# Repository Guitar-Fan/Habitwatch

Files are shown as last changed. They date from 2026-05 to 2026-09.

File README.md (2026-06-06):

# Habitwatch

This is the Habitwatch, a custom designed smartwatch for keep track of habits. It uses an Xiao ESP-32-C6 4.0 development board, compact enough to fit in a small sized enclosure, while having many features. The main function is a highly customizable reminder/alarm system, that works along side a integrated vibration motor to remind you to keep all habits you want. The firmware also allows users to customize the motor to produce a custom monophonic ringtone. Extra features include connectivity with devices via wifi, bluetooth, etc... All electronics are smarly housed in a custom-designed 3D-printed compact enclosure (with a reasonable size for a watch).

I made this project because I know first-hand the difficulty of upholding good habits, and wanted to make a project to help out with a common life problem. I also wanted this watch to be truely useful to everyday life.

## Images

### Schematic
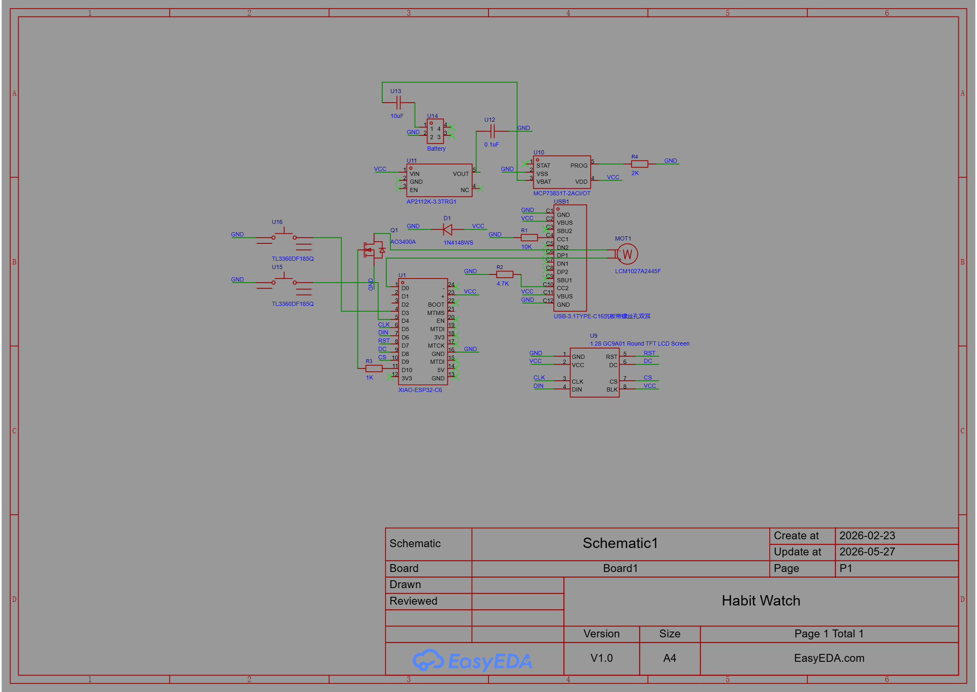
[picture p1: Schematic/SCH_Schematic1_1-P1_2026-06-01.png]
Wiring Diagram

*Complete wiring diagram showing all connections*

### PCB Design
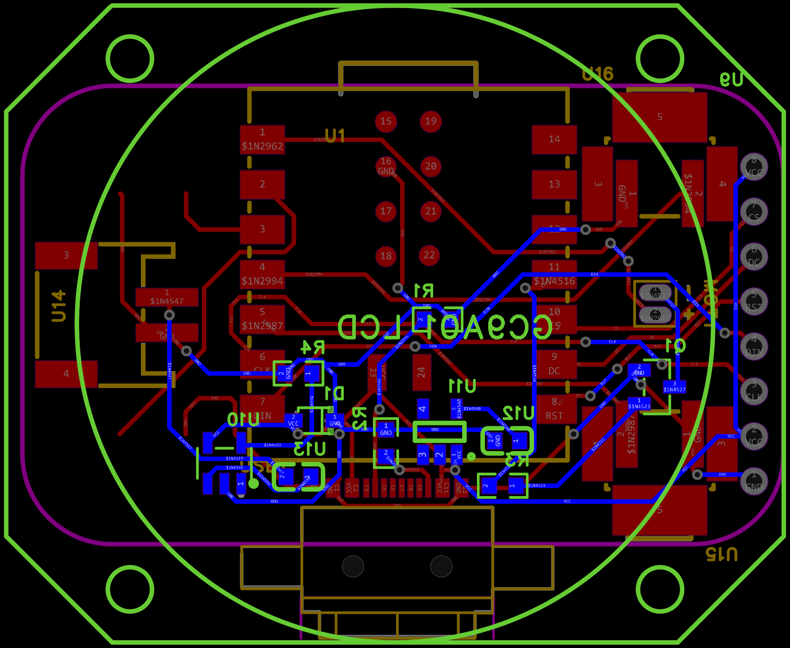
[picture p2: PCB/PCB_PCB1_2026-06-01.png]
PCB Layout

*Custom PCB design for the Habitwatch circuit*

### 3D Enclosure - Front
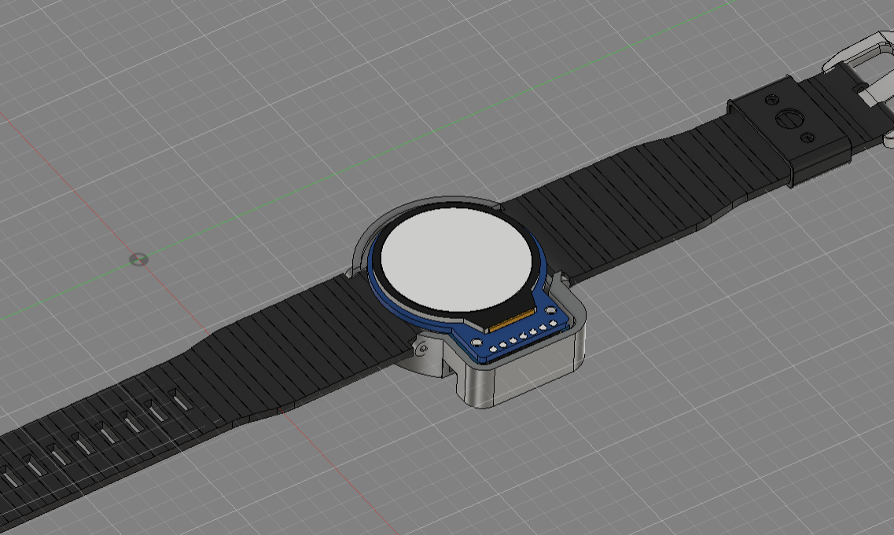
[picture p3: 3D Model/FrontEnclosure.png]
3D Build Model Front with Enclosure

*Custom-designed 3D-printed enclosure front view*

### 3D Enclosure - Back
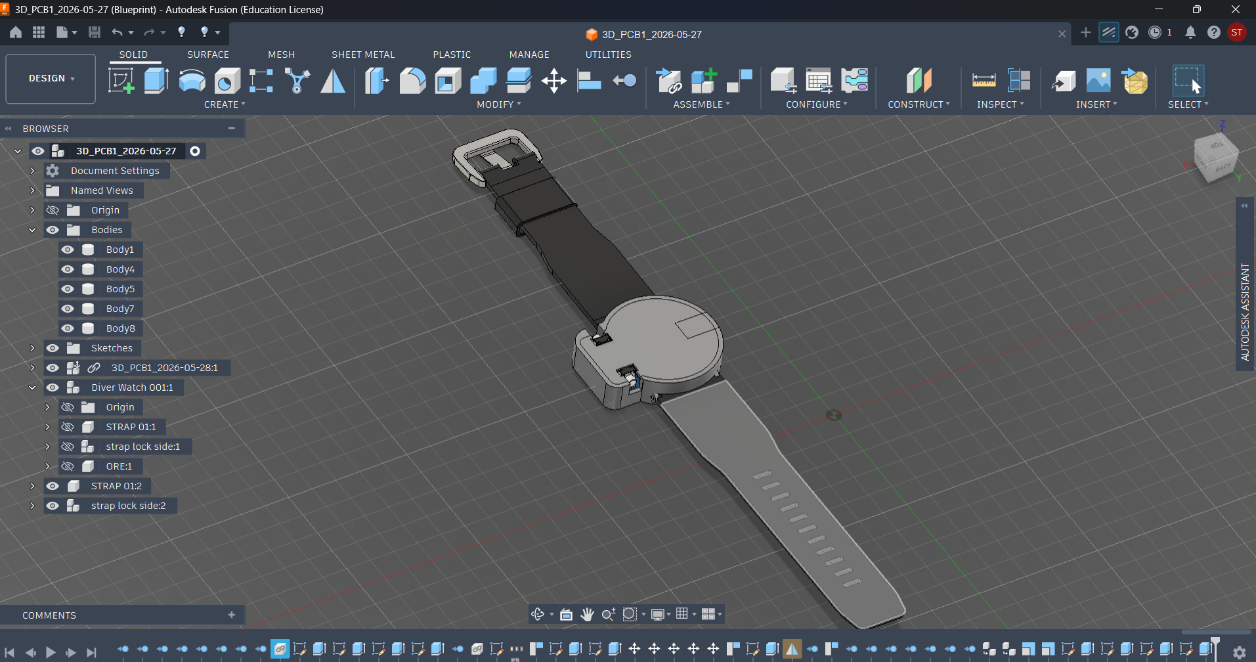
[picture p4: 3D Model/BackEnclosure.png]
3D Build Model Back with Enclosure

*Custom-designed 3D-printed enclosure back view*

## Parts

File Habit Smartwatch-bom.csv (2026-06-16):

Name | Purpose | Quantity | Total Cost (USD) | Link | Distributor
CR0603-JW-102ELF | 1K resistor | 1 | 0.10 | https://www.digikey.com/en/products/detail/bourns-inc/CR0603-JW-102ELF/3741004 | Digikey
CR0603-JW-202ELF | 2K resistor | 1 | 0.10 | https://www.digikey.com/en/products/detail/bourns-inc/CR0603-JW-202ELF/3784319 | Digikey
CR0603-JW-472ELF | 4.7K Resistor | 1 | 0.10 | https://www.digikey.com/en/products/detail/bourns-inc/CR0603-JW-472ELF/3593210 | Digikey
CR0603-FX-1002ELF | 10K Chip Resistor | 1 | 0.10 | https://www.digikey.com/en/products/detail/bourns-inc/CR0603-FX-1002ELF/3593188 | Digikey
1N4148WS | Diode | 1 | 0.18 | https://www.digikey.com/en/products/detail/onsemi/1n4148ws/1873805 | Digikey
AP2112K-2.5TRG1 | Voltage Regulator | 1 | 0.23 | https://www.digikey.com/en/products/detail/diodes-incorporated/AP2112K-2-5TRG1/5305549 | Digikey
MCP73831T-2ACI/OT | Battery IC | 1 | 0.76 | https://www.digikey.com/en/products/detail/microchip-technology/mcp73831t-2aci-ot/964301 | Digikey
10164359-00011LF | USB-C Receptacle | 1 | 0.48 | https://www.digikey.com/en/products/detail/amphenol-cs-fci/10164359-00011LF/18443702 | Digikey
3.7V 200mAh 602025 Lipo Battery Rechargeable Lithium Polymer ion Battery Pack with PH2.0mm JST Connector | Lipo Battery | 1 | 6.99 | https://www.amazon.com/battery-Rechargeable-Lithium-Polymer-Connector/dp/B07C9R84QS?th=1 | Amazon
AO3400A | Mosfet | 1 | 0.52 | https://www.digikey.com/en/products/detail/alpha-omega-semiconductor-inc/ao3400a/1855772 | Digikey
FIT0774 | Vibration Motor | 1 | 0.99 | https://www.digikey.com/en/products/detail/dfrobot/FIT0774/14322639 | Digikey
TL3360DF185Q | Push Buttons | 2 | 2.20 | https://www.digikey.com/en/products/detail/e-switch/TL3360DF185Q/5816190 | Digikey
PCB | PCB | 1 | 5.10 |  | JLCPCB
GC9A01 TFT Display 1.28 Inch TFT LCD Display Module | Display | 1 | 3.04 | https://www.aliexpress.us/item/3256804295713253.html?curPageLogUid=uTnJoR09Xv6y | Aliexpress
XIAO ESP32C6 | Microcontroller | 1 | 9.28 | https://www.aliexpress.us/item/3256807240718259.html?gatewayAdapt=glo2usa4itemAdapt | Aliexpress

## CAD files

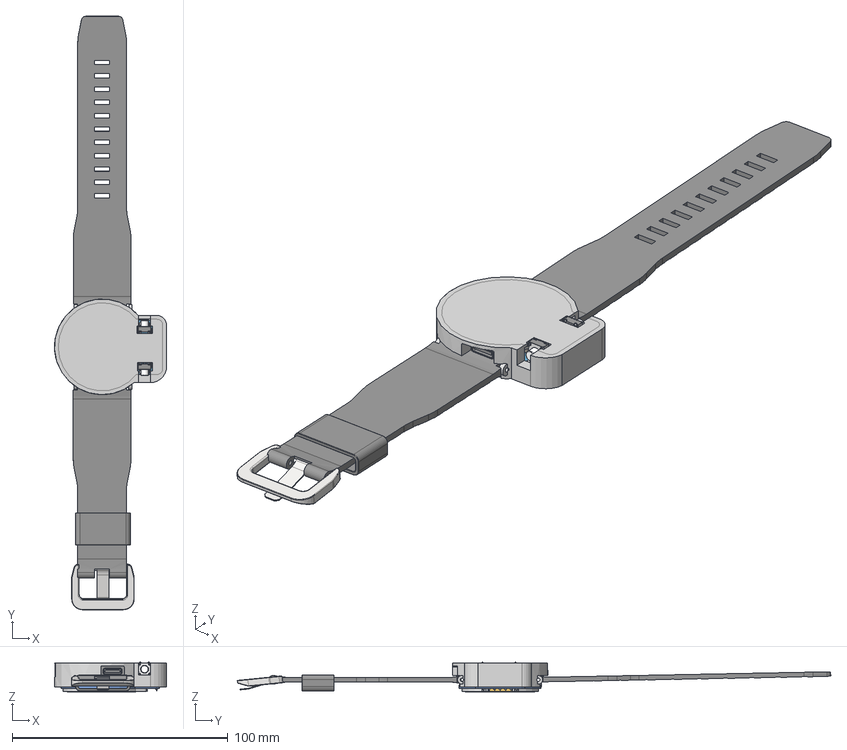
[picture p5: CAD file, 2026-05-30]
3D Model/HabitwatchEnclosureSTEP.step
51.9 x 275.3 x 13.9 mm

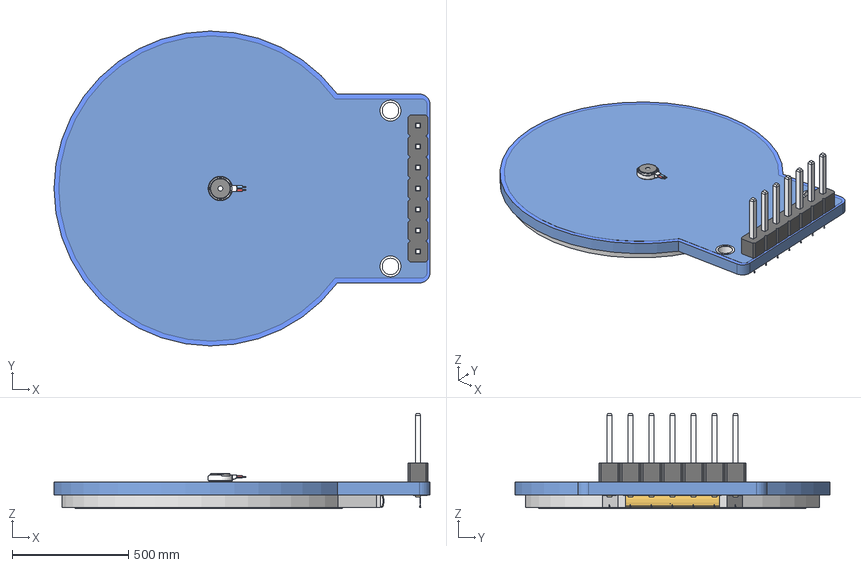
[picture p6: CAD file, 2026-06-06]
PCB/3D_PCB1_2026-06-01.step
1617.3 x 1354.2 x 409.2 mm
Board~56Qw
TopCopper~56Qw
BottomCopper~56Qw
TopSilkscreen~56Qw
BottomSilkscreen~56Qw
TopFpcStiffener~56Qw
BottomFpcStiffener~56Qw
R0603~R0603~7GvT x 4
SOT-23-3_L2.9-W1.3-P1.90-LS2.4-BR~SOT-23-3P_L2.9-W1.3-H1.0-LS2.4-P0.95~N2Kr
SOT-23-5_L3.0-W1.7-P0.95-LS2.8-BL~SOT-23-5_L2.9-W1.6-H1.1-LS2.8-P0.95~ODiN
VIBRATING-MOTOR-SMD_WELDING~VIBRATING-MOTOR-SMD_WELDING~XiWm
SOD-323_L1.8-W1.3-LS2.5-RD~SOD-323_L1.8-W1.3-LS2.5-RD~C2Tw
GC9A01 TFT LCD SCREEN~Teyleten Robot 1.28 Inch GC9A01 240x240 v1~5Ysm x 23
SOT-25-5_L2.9-W1.6-P0.95-LS2.8-BL~SOT-25-5_L2.9-W1.6-P0.95-LS2.8-BL~uqKM
C0603~C0603_L1.6-W0.8-H0.8~fYWC x 2
CONN-SMD_2.0-2PWT~CONN-SMD_2.0-2PWT~AiJI
LCC-14P_L17.7-W20.8-XIAO-ESP32-C6~Seeed Studio XIAO ESP32-C6~7Vn3 x 29
SW-SMD_TL3360BF185Q~SW-SMD_TL3360BF185Q~0CVZ x 2
USB-C-SMD_USB-3.1TYPE-C16~USB-C-SMD_USB-3.1TYPE-C16~z4gI

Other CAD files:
3D Model/Habitwatch Step 3d model with PCB.f3z

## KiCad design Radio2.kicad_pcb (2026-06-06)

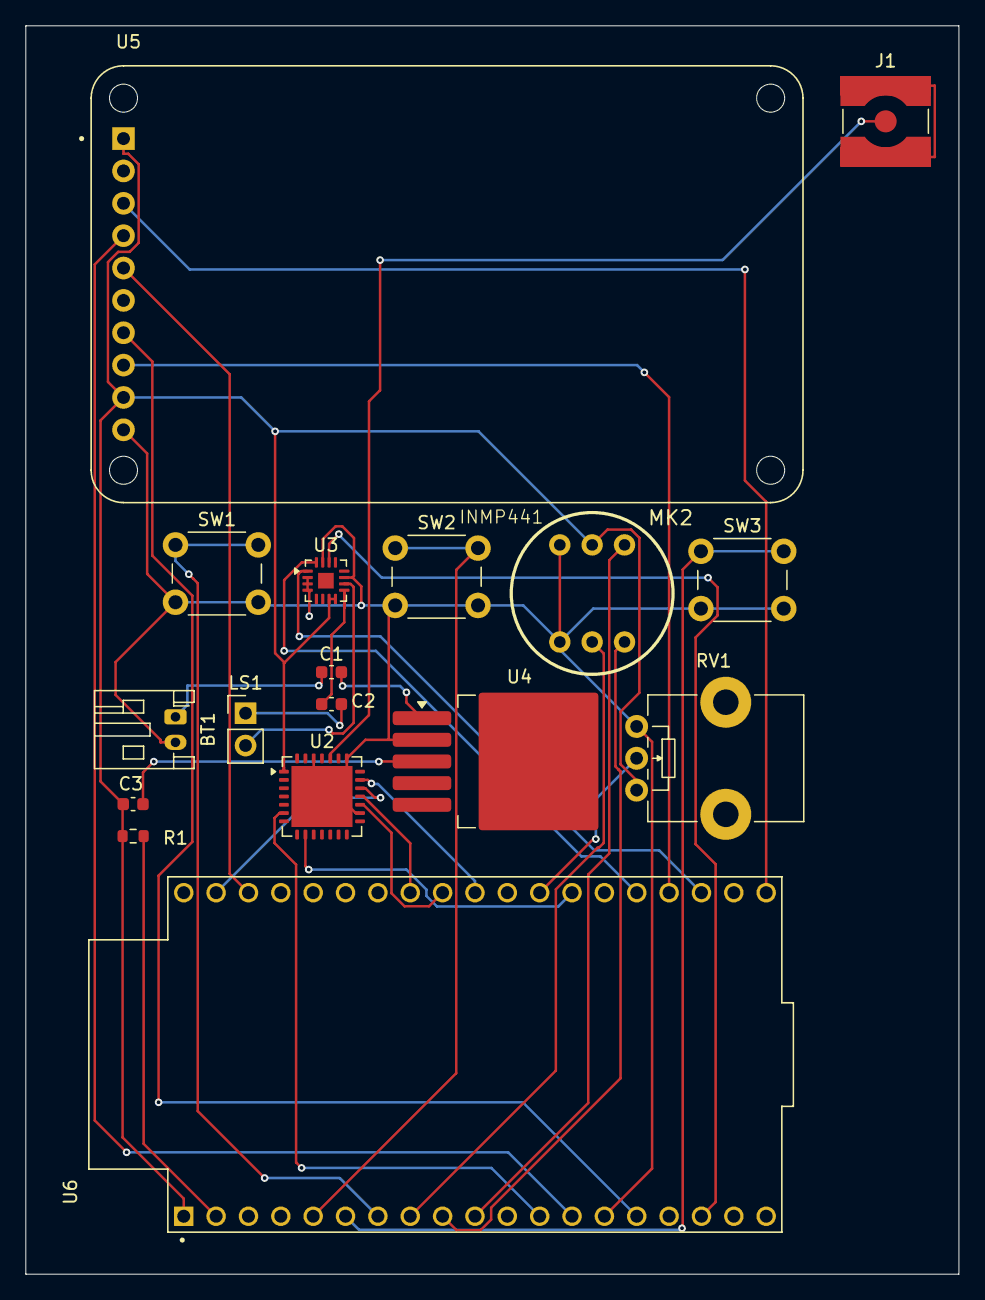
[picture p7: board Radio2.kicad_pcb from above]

Board: 2 copper layers, 73.2 x 98.0 mm, 17 parts (0 on the bottom side), 31 nets.

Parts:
BT1: LiPo 3.7V 2000mAh (Adafruit #2011); JST_PH_S2B-PH-K_1x02_P2.00mm_Horizontal
C1: 10 µF; C_0603_1608Metric
C2, C3: 100 nF; C_0603_1608Metric
J1: Conn_Coaxial; SMA_Amphenol_132134-10_Vertical
LS1: 8Ω 0.5W speaker; PinHeader_1x02_P2.54mm_Vertical
MK2: INMP441
R1: 10 kΩ; R_0603_1608Metric
RV1: R_Potentiometer; Potentiometer_Bourns_PTV09A-1_Single_Vertical
SW1, SW2, SW3: SW_Push; SW_PUSH_6mm
U2: SX1272; QFN-28-1EP_6x6mm_P0.65mm_EP4.8x4.8mm
U3: MAX98357A; TQFN-16-1EP_3x3mm_P0.5mm_EP1.23x1.23mm
U4: MCP1826S; TO-263-5_TabPin6
U5: Industrial Monitor, Color LCD TFT, 1.8 in, 128 x 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; MODULE_358
U6: ESP32-DEVKITC V4; MODULE_ESP32-DEVKITC

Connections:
+3V3: C3.1, MK2.5 (3V3), R1.1, RV1.1, U2.1 (VBAT1), U3.7 (VDD), U3.8 (VDD), U5.1 (LITE), U5.9 (VCC), U6.1 (3V3)
GND: BT1.2 (-), MK2.1 (L/R), MK2.4 (GND), RV1.3, SW1.2, SW2.2, SW3.2, U2.16 (GND), U2.22 (GND), U2.26 (GND), U2.29 (GND), U3.2 (GAIN_SLOT), U3.3 (GND), U3.4 (~SD_MODE), U3.11 (GND), U3.15 (GND), U4.2 (GND), U5.10 (GND), U6.14 (GND1)
unnamed: BT1.1 (+), C1.1
unnamed: C2.2, LS1.1
unnamed: J1.1 (In), U2.24 (RFO)
unnamed: MK2.3 (SCK), U6.9 (IO25)
unnamed: MK2.6 (SD), U6.10 (IO26)
unnamed: MK2.2 (WS), U6.8 (IO33)
unnamed: U2.9 (DIO0), U6.26 (IO4)
unnamed: U2.18 (MISO), U6.31 (IO19)
unnamed: U2.19 (MOSI), U6.37 (IO23)
unnamed: U2.20 (NSS), U6.29 (IO5)
unnamed: U2.17 (SCK), U6.30 (IO18)
unnamed: U2.6 (~RESET), U6.12 (IO14)
unnamed: U3.16 (BCLK), U6.24 (IO2)
unnamed: U3.1 (DIN), U6.22 (SD1)
unnamed: U3.14 (LRCLK), U6.17 (SD3)
unnamed: LS1.2, U3.10 (OUTN)
unnamed: C2.1, U3.9 (OUTP)
unnamed: C1.2, U4.1 (VI)
unnamed: C3.2, U4.3 (VO)
unnamed: U5.7 (D/C), U6.15 (IO13)
unnamed: U5.4 (MOSI), U6.13 (IO12)
unnamed: U5.8 (RESET), U6.23 (IO15)
unnamed: U5.3 (SCK), U6.20 (CLK)
unnamed: U5.5 (TFT_CS), U6.36 (IO22)
unnamed: R1.2, U6.2 (EN)
unnamed: RV1.2, U6.27 (IO16)
unnamed: SW1.1, U6.7 (IO32)
unnamed: SW2.1, U6.5 (IO34)
unnamed: SW3.1, U6.6 (IO35)

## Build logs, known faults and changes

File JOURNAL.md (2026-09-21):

<!--
  This journal is auto generated by Stasis.
-->

# 5/30/2026 12 AM - Finished CAD for Habitwatch

_Time spent: 3h_




Designed the enclosure for the Habitwatch in Fusion 360. Most of the difficulty was making appropriate spacing for the sticking out components of my PCB, such as the ports and buttons. Imported a watch step model from Grabcad and attached the strap to the case. I'm planning to print the strap with TPU for built-in flexibility.




# 5/15/2026 10 PM - Simplified Schematic complete, PCB complete

_Time spent: 4h_

Screenshot 2026-05-15 1.57.44 PM

Screenshot 2026-05-15 1.59.50 PM

SCH_Schematic1_1-P1_2026-05-15

Screenshot 2026-05-15 1.57.25 PM

I massively simplified and excluded extra features I didn't need, such as the GPS, to just keep the core functionality. I switched from an MCU microchip to and Xiao ESP32-C6 and deleted the bio-measurement components. I only kept the vibrator, as that was the component that was most important to making this watch be an effective reminder. I added power protection and charging components, and a USB-C port. 

Then, I wired the components together starting with the ESP32-C6 wirings for the main functions, and the adding passives and wiring the power system. I used mostly net labels.

Then, I converted the schematic into a PCB using the Easyeda feature. I strategically placed the screen and main components on opposite sides to make the PCB compact enough for a watch. Then I autorouted.

Then, I exported appropriate files






# 12/26/2025 1 AM - Carefully researched and selected components

_Time spent: 3h_

I chose components that were one of the best of its kind. For example, I chose the MAX-M10M-00B GPS instead of a generic Max M8n GPS for higher accuracy and speed. I included a component for every smart feature a high-end modern smartwatch has.



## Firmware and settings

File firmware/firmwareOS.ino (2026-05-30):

/* =========================================================================
 *  HabitWatch OS v2.1 - Complete Smartwatch Operating System (Fixed)
 *  Target: Seeed Studio XIAO ESP32-C6 + GC9A01 TFT + Custom Vibrator
 *
 *  Fixes Applied:
 *  [1] Vibrator pattern index off-by-one & sentinel logic rewritten
 *  [2] Button events now use bitmask - both buttons captured per cycle
 *  [3] Removed blocking delay(2000) in STATE_SNOOZE - non-blocking timer
 *  [4] Habit trigger uses 5-second window + lastTriggeredMinute guard
 *  [5] wakeUpScreen() removed from readButtons() - input layer is pure
 *  [6] Snooze timer uses start+elapsed pattern (millis overflow safe)
 *  [7] STATE_SLEEP now blocks habit engine
 *  [8] Battery calc uses integer millivolts - no float precision loss
 *  [9] Mock time fallback zero-initializes struct tm before use
 *  [10] Global back nav uses consumed flag instead of modifying local copy
 * =========================================================================*/

#include <TFT_eSPI.h>
#include <SPI.h>
#include <WiFi.h>
#include <time.h>
#include <esp_sleep.h>

// =========================================================================
// CONFIGURATION & CREDENTIALS
// =========================================================================
const char* ssid              = "YOUR_WIFI_SSID";
const char* password          = "YOUR_WIFI_PASSWORD";
const char* ntpServer         = "pool.ntp.org";
const long  gmtOffset_sec     = -28800; // PST (-8h). Adjust for your timezone.
const int   daylightOffset_sec = 3600;

// =========================================================================
// HARDWARE PINS
// =========================================================================
#define MOTOR_PIN   D1   // AO3400A MOSFET Gate
#define BTN_NEXT    D2   // Button 1 (Navigate / Snooze)
#define BTN_SELECT  D3   // Button 2 (Select / Dismiss)
#define TFT_BL_PIN  D10  // Backlight PWM Control
#define BATTERY_PIN A0   // ADC pin (requires 1/2 voltage divider on hardware)

// =========================================================================
// DISPLAY SETTINGS & COLORS (RGB565)
// =========================================================================
TFT_eSPI tft = TFT_eSPI();

#define C_BG        0x0821  // Deep dark blue
#define C_ACCENT    0x07E0  // Bright green
#define C_ALERT     0xF800  // Vibrant red
#define C_TEXT      0xFFFF  // White
#define C_MUTED     0x4A49  // Dim grey
#define C_BATT_GOOD 0x07E0  // Green
#define C_BATT_LOW  0xF800  // Red

// =========================================================================
// SYSTEM STATES
// =========================================================================
enum AppState {
  STATE_BOOT,
  STATE_WATCHFACE,
  STATE_MENU,
  STATE_HABIT_SETTINGS,
  STATE_SYS_SETTINGS,
  STATE_ALARM,
  STATE_SNOOZE,
  STATE_SLEEP
};
AppState currentState = STATE_BOOT;

// =========================================================================
// SYSTEM VARIABLES
// =========================================================================
int  screenBrightness  = 200;   // 0-255 PWM
int  batteryPercent    = 100;
bool wifiConnected     = false;
bool forceRedraw       = true;

unsigned long lastActivityTime  = 0;
unsigned long snoozeDisplayTimer = 0; // [FIX 3] replaces blocking delay()

const unsigned long SCREEN_TIMEOUT_MS = 15000; // 15 seconds

// =========================================================================
// MENU SYSTEM
// =========================================================================
const char* mainMenuItems[] = { "Habits", "Settings", "Sync Time", "Sleep" };
const int   numMenuItems    = 4;
int currentMenuIndex        = 0;
int habitMenuIndex          = 0;

// =========================================================================
// VIBRATION ENGINE
// =========================================================================
// Sentinel values for pattern control:
//   intensity == -1  → loop back to index 0
//   intensity == -2  → stop (end of pattern)
struct VibeStep {
  int intensity;  // 0-255 PWM, -1 = loop, -2 = end
  int duration;   // milliseconds
};

// [FIX 1] All patterns now use explicit -2 end sentinel
VibeStep pat_Water[]   = { {150,150},{0,100},{150,150},{0,1000},{-1,0} };
VibeStep pat_Posture[] = { {255,400},{0,200},{100,400},{0,1500},{-1,0} };
VibeStep pat_Pill[]    = { {200,100},{0,50},{200,100},{0,50},{200,100},{0,2000},{-1,0} };
VibeStep pat_Snooze[]  = { {80,50},{0,50},{80,50},{0,3000},{-1,0} };
VibeStep pat_Tick[]    = { {100,30},{-2,0} }; // Single pulse then stop

VibeStep*     currentPattern = nullptr;
int           patternIndex   = 0;
unsigned long patternTimer   = 0;

void playVibe(VibeStep* pattern) {
  currentPattern = pattern;
  patternIndex   = 0;
  patternTimer   = millis();
  analogWrite(MOTOR_PIN, currentPattern[0].intensity);
}

void stopVibe() {
  currentPattern = nullptr;
  analogWrite(MOTOR_PIN, 0);
}

// [FIX 1] Rewrote sentinel logic: check -1 (loop) and -2 (end) clearly,
//         increment index first then bounds-check before any analogWrite.
void updateVibrator() {
  if (!currentPattern) return;
  if (millis() - patternTimer < (unsigned long)currentPattern[patternIndex].duration) return;

  patternIndex++;

  int nextIntensity = currentPattern[patternIndex].intensity;

  if (nextIntensity == -1) {
    // Loop sentinel: restart from beginning
    patternIndex  = 0;
    nextIntensity = currentPattern[0].intensity;
  } else if (nextIntensity == -2) {
    // End sentinel: stop vibrator entirely
    stopVibe();
    return;
  }

  patternTimer = millis();
  analogWrite(MOTOR_PIN, nextIntensity);
}

// =========================================================================
// HABIT ENGINE
// =========================================================================
struct Habit {
  String        name;
  int           triggerMinute;      // Fires at xx:triggerMinute each hour
  int           snoozeMins;
  VibeStep*     pattern;
  bool          active;
  bool          justSnoozed;
  unsigned long snoozeStartMs;      // [FIX 6] store START not target
  int           lastTriggeredMinute; // [FIX 4] prevents re-trigger in same minute
};

// lastTriggeredMinute initialised to -1 so it never falsely matches minute 0
Habit habits[] = {
  { "Drink Water", 0,  5,  pat_Water,   true,  false, 0, -1 },
  { "Posture",     30, 5,  pat_Posture, true,  false, 0, -1 },
  { "Take Pill",   15, 10, pat_Pill,    false, false, 0, -1 }
};
const int NUM_HABITS = sizeof(habits) / sizeof(Habit);

int activeHabitIndex = 0;

// Forward declarations needed by updateHabitEngine
void wakeUpScreen();

// [FIX 4] 5-second trigger window + lastTriggeredMinute guard
// [FIX 7] Returns immediately when STATE_SLEEP is active
void updateHabitEngine(struct tm* timeinfo) {
  if (currentState == STATE_ALARM  ||
      currentState == STATE_SNOOZE ||
      currentState == STATE_SLEEP) return;  // [FIX 7]

  unsigned long now = millis();

  for (int i = 0; i < NUM_HABITS; i++) {
    if (!habits[i].active) continue;

    // --- Standard minute trigger ---
    // [FIX 4] 5-second window + de-duplicate within same minute
    if (!habits[i].justSnoozed &&
        timeinfo->tm_min == habits[i].triggerMinute &&
        timeinfo->tm_sec < 5 &&
        habits[i].lastTriggeredMinute != timeinfo->tm_min) {

      habits[i].lastTriggeredMinute = timeinfo->tm_min;
      activeHabitIndex = i;
      currentState     = STATE_ALARM;
      playVibe(habits[i].pattern);
      forceRedraw = true;
      wakeUpScreen();
      break;
    }

    // --- Snooze expiry trigger ---
    // [FIX 6] elapsed subtraction is overflow-safe
    if (habits[i].justSnoozed) {
      unsigned long elapsed = now - habits[i].snoozeStartMs;
      unsigned long target  = (unsigned long)habits[i].snoozeMins * 60000UL;
      if (elapsed >= target) {
        habits[i].justSnoozed = false;
        activeHabitIndex = i;
        currentState     = STATE_ALARM;
        playVibe(habits[i].pattern);
        forceRedraw = true;
        wakeUpScreen();
        break;
      }
    }
  }
}

// =========================================================================
// INPUT ENGINE
// =========================================================================

// [FIX 2] Bitmask-based event system: both buttons captured in one call.
//         No event is silently overwritten.
#define EVT_NONE       0x00
#define EVT_NEXT_SHORT 0x01
#define EVT_NEXT_LONG  0x02
#define EVT_SEL_SHORT  0x04
#define EVT_SEL_LONG   0x08
#define EVT_ANY_PRESS  0x10  // [FIX 5] raw press detected (for wakeUpScreen)

struct Button {
  uint8_t       pin;
  bool          lastState;
  unsigned long pressTime;
  bool          handledLongPress;
};

Button btnNext = { BTN_NEXT,   HIGH, 0, false };
Button btnSel  = { BTN_SELECT, HIGH, 0, false };

// [FIX 2] Returns bitmask of all events that occurred this cycle.
// [FIX 5] wakeUpScreen() is NO LONGER called here; caller handles EVT_ANY_PRESS.
uint8_t readButtons() {
  uint8_t       events = EVT_NONE;
  unsigned long now    = millis();

  // ---- NEXT button ----
  bool curNext = digitalRead(btnNext.pin);

  if (curNext == LOW && btnNext.lastState == HIGH) {
    // Just pressed
    btnNext.pressTime        = now;
    btnNext.handledLongPress = false;
    events |= EVT_ANY_PRESS;
  } else if (curNext == LOW && btnNext.lastState == LOW) {
    // Held down
    if (!btnNext.handledLongPress && (now - btnNext.pressTime > 600)) {
      events |= EVT_NEXT_LONG;
      btnNext.handledLongPress = true;
    }
  } else if (curNext == HIGH && btnNext.lastState == LOW) {
    // Released
    if (!btnNext.handledLongPress && (now - btnNext.pressTime > 50)) {
      events |= EVT_NEXT_SHORT;
    }
  }
  btnNext.lastState = curNext;

  // ---- SELECT button ----
  bool curSel = digitalRead(btnSel.pin);

  if (curSel == LOW && btnSel.lastState == HIGH) {
    // Just pressed
    btnSel.pressTime        = now;
    btnSel.handledLongPress = false;
    events |= EVT_ANY_PRESS;
  } else if (curSel == LOW && btnSel.lastState == LOW) {
    // Held down
    if (!btnSel.handledLongPress && (now - btnSel.pressTime > 600)) {
      events |= EVT_SEL_LONG;
      btnSel.handledLongPress = true;
    }
  } else if (curSel == HIGH && btnSel.lastState == LOW) {
    // Released
    if (!btnSel.handledLongPress && (now - btnSel.pressTime > 50)) {
      events |= EVT_SEL_SHORT;
    }
  }
  btnSel.lastState = curSel;

  return events;
}

// =========================================================================
// POWER & SYSTEM MANAGEMENT
// =========================================================================

// [FIX 5] wakeUpScreen() is now only called from the main loop,
//         never from inside readButtons().
void wakeUpScreen() {
  lastActivityTime = millis();
  if (currentState == STATE_SLEEP) {
    analogWrite(TFT_BL_PIN, screenBrightness);
    currentState = STATE_WATCHFACE;
    forceRedraw  = true;
  }
}

void goToSleep() {
  currentState = STATE_SLEEP;
  analogWrite(TFT_BL_PIN, 0);
  tft.fillScreen(TFT_BLACK);
  stopVibe();
}

// [FIX 8] Integer millivolt arithmetic – no float precision loss in map()
void updateBattery() {
  int  raw        = analogRead(BATTERY_PIN);
  long millivolts = ((long)raw * 3300L * 2L) / 4095L; // 1/2 divider assumed
  batteryPercent  = (int)map(millivolts, 3200L, 4200L, 0L, 100L);
  batteryPercent  = constrain(batteryPercent, 0, 100);
}

void syncTime() {
  tft.fillScreen(C_BG);
  tft.setTextDatum(MC_DATUM);
  tft.setTextColor(C_TEXT);
  tft.drawString("Syncing WiFi...", 120, 120, 2);

  WiFi.begin(ssid, password);
  int attempts = 0;
  while (WiFi.status() != WL_CONNECTED && attempts < 20) {
    delay(500);
    attempts++;
  }

  if (WiFi.status() == WL_CONNECTED) {
    wifiConnected = true;
    configTime(gmtOffset_sec, daylightOffset_sec, ntpServer);
    tft.setTextColor(C_ACCENT);
    tft.drawString("Time Synced!", 120, 150, 2);
    delay(1000);
    WiFi.disconnect(true);
    WiFi.mode(WIFI_OFF);
  } else {
    wifiConnected = false;
    tft.setTextColor(C_ALERT);
    tft.drawString("Sync Failed", 120, 150, 2);
    delay(1000);
  }
}

// =========================================================================
// UI / DRAWING FUNCTIONS
// =========================================================================
void drawStatusBar() {
  // Battery icon (outline + nub)
  tft.drawRect(105, 10, 24, 10, C_MUTED);
  tft.fillRect(129, 13, 2, 4, C_MUTED);

  uint16_t bColor = (batteryPercent > 20) ? C_BATT_GOOD : C_BATT_LOW;
  int      bWidth = map(batteryPercent, 0, 100, 0, 20);
  tft.fillRect(107, 12, bWidth, 6, bColor);

  // WiFi dot
  if (wifiConnected) {
    tft.fillCircle(145, 18, 2, C_ACCENT);
    tft.drawArc(145, 18, 6, 4, 220, 320, C_ACCENT, C_BG);
  }
}

void drawWatchFace(struct tm* timeinfo) {
  tft.fillScreen(C_BG);
  drawStatusBar();

  tft.drawCircle(120, 120, 118, C_ACCENT);
  tft.drawCircle(120, 120, 117, C_MUTED);

  tft.setTextDatum(MC_DATUM);

  // HH:MM
  char timeStr[10];
  strftime(timeStr, sizeof(timeStr), "%H:%M", timeinfo);
  tft.setTextColor(C_TEXT, C_BG);
  tft.drawString(timeStr, 120, 110, 7);

  // Date
  char dateStr[20];
  strftime(dateStr, sizeof(dateStr), "%a, %b %d", timeinfo);
  tft.setTextColor(C_MUTED, C_BG);
  tft.drawString(dateStr, 120, 160, 2);

  // Next active habit preview
  for (int i = 0; i < NUM_HABITS; i++) {
    if (habits[i].active) {
      tft.setTextColor(C_ACCENT, C_BG);
      String preview = habits[i].name + " @ xx:" + String(habits[i].triggerMinute);
      tft.drawString(preview, 120, 190, 2);
      break;
    }
  }
}

void drawMainMenu() {
  tft.fillScreen(C_BG);
  tft.setTextDatum(MC_DATUM);

  tft.setTextColor(C_ACCENT, C_BG);
  tft.drawString("MAIN MENU", 120, 40, 2);

  tft.setTextColor(C_TEXT, C_BG);
  tft.drawString(mainMenuItems[currentMenuIndex], 120, 120, 4);

  tft.setTextColor(C_MUTED, C_BG);
  tft.drawString("[Nxt] Scroll", 120, 180, 2);
  tft.drawString("[Sel] Enter ", 120, 200, 2);

  // Pagination dots
  for (int i = 0; i < numMenuItems; i++) {
    if (i == currentMenuIndex)
      tft.fillCircle(90 + (i * 20), 150, 4, C_TEXT);
    else
      tft.drawCircle(90 + (i * 20), 150, 4, C_MUTED);
  }
}

void drawHabitsApp() {
  tft.fillScreen(C_BG);
  tft.setTextDatum(MC_DATUM);

  tft.setTextColor(C_ACCENT, C_BG);
  tft.drawString("HABITS", 120, 40, 2);

  tft.setTextColor(C_TEXT, C_BG);
  tft.drawString(habits[habitMenuIndex].name, 120, 100, 4);

  if (habits[habitMenuIndex].active) {
    tft.fillRoundRect(80, 130, 80, 30, 15, C_ACCENT);
    tft.setTextColor(C_BG);
    tft.drawString("ACTIVE", 120, 145, 2);
  } else {
    tft.fillRoundRect(80, 130, 80, 30, 15, C_MUTED);
    tft.setTextColor(C_TEXT);
    tft.drawString("OFF", 120, 145, 2);
  }

  tft.setTextColor(C_MUTED, C_BG);
  tft.drawString("[Nxt] Cycle | [Sel] Toggle", 120, 200, 2);
}

void drawAlarmScreen() {
  tft.fillScreen(C_ALERT);
  tft.drawCircle(120, 120, 110, C_TEXT);
  tft.drawCircle(120, 120, 108, C_TEXT);

  tft.setTextDatum(MC_DATUM);
  tft.setTextColor(C_TEXT, C_ALERT);
  tft.drawString("ACTION!", 120, 70, 4);
  tft.drawString(habits[activeHabitIndex].name, 120, 120, 4);

  // Snooze button (left)
  tft.fillRoundRect(30, 170, 80, 30, 10, C_TEXT);
  tft.setTextColor(C_ALERT, C_TEXT);
  tft.drawString("SNOOZE", 70, 185, 2);

  // Dismiss button (right)
  tft.fillRoundRect(130, 170, 80, 30, 10, C_TEXT);
  tft.setTextColor(C_ALERT, C_TEXT);
  tft.drawString("DISMISS", 170, 185, 2);
}

void drawSnoozeScreen() {
  tft.fillScreen(C_BG);
  tft.setTextDatum(MC_DATUM);
  tft.setTextColor(C_MUTED, C_BG);
  tft.drawString("Snoozed for", 120, 90, 2);
  tft.setTextColor(C_ACCENT, C_BG);
  tft.drawString(String(habits[activeHabitIndex].snoozeMins) + " mins", 120, 130, 4);
}
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
void loop() {

  // ------------------------------------------------------------------
  // 1. Time
  // ------------------------------------------------------------------
  struct tm timeinfo;

  if (!getLocalTime(&timeinfo)) {
    // [FIX 9] Zero-init entire struct before populating mock fields
    memset(&timeinfo, 0, sizeof(timeinfo));
    unsigned long ms   = millis();
    timeinfo.tm_hour   = (ms / 3600000UL) % 24;
    timeinfo.tm_min    = (ms / 60000UL)   % 60;
    timeinfo.tm_sec    = (ms / 1000UL)    % 60;
    timeinfo.tm_mday   = 1;   // sane date fallback
    timeinfo.tm_mon    = 0;
    timeinfo.tm_year   = 124; // 2024
  }

  // ------------------------------------------------------------------
  // 2. Hardware updates (non-blocking)
  // ------------------------------------------------------------------
  updateVibrator();
  updateHabitEngine(&timeinfo);

  static unsigned long lastBattCheck = 0;
  if (millis() - lastBattCheck > 60000UL) {
    updateBattery();
    lastBattCheck = millis();
  }

  // ------------------------------------------------------------------
  // 3. Screen timeout / power management
  // ------------------------------------------------------------------
  if (currentState != STATE_SLEEP && currentState != STATE_ALARM) {
    if (millis() - lastActivityTime > SCREEN_TIMEOUT_MS) {
      goToSleep();
    }
  }

  // ------------------------------------------------------------------
  // 4. Input (pure read - no side effects inside readButtons)
  // ------------------------------------------------------------------
  uint8_t events = readButtons();

  // [FIX 5] Wake-up handled here, not inside readButtons()
  if (events & EVT_ANY_PRESS) {
    wakeUpScreen();
  }

  // ------------------------------------------------------------------
  // 5. Global back navigation (SEL long-press from any non-root state)
  // ------------------------------------------------------------------
  // [FIX 10] Use a consumed flag so the switch below sees clean state
  bool eventConsumed = false;

  if ((events & EVT_SEL_LONG) &&
       currentState != STATE_WATCHFACE &&
       currentState != STATE_ALARM) {
    currentState   = STATE_WATCHFACE;
    forceRedraw    = true;
    eventConsumed  = true;
    playVibe(pat_Tick);
  }

  if (eventConsumed) return; // Skip state machine this cycle

  // ------------------------------------------------------------------
  // 6. State machine
  // ------------------------------------------------------------------
  switch (currentState) {

    // ----------------------------------------------------------------
    case STATE_WATCHFACE: {
      if (events & (EVT_SEL_SHORT | EVT_NEXT_SHORT)) {
        currentState     = STATE_MENU;
        currentMenuIndex = 0;
        forceRedraw      = true;
      } else {
        static int lastSec = -1;
        if (timeinfo.tm_sec != lastSec || forceRedraw) {
          drawWatchFace(&timeinfo);
          lastSec     = timeinfo.tm_sec;
          forceRedraw = false;
        }
      }
      break;
    }

    // ----------------------------------------------------------------
    case STATE_MENU: {
      if (forceRedraw) { drawMainMenu(); forceRedraw = false; }

      if (events & EVT_NEXT_SHORT) {
        currentMenuIndex = (currentMenuIndex + 1) % numMenuItems;
        forceRedraw = true;

      } else if (events & EVT_SEL_SHORT) {
        switch (currentMenuIndex) {
          case 0: // Habits
            currentState   = STATE_HABIT_SETTINGS;
            habitMenuIndex = 0;
            forceRedraw    = true;
            break;

          case 1: // Settings (brightness toggle)
            screenBrightness = (screenBrightness == 200) ? 50 : 200;
            analogWrite(TFT_BL_PIN, screenBrightness);
            playVibe(pat_Tick);
            forceRedraw = true;
            break;

          case 2: // Sync time
            syncTime();
            currentState = STATE_WATCHFACE;
            forceRedraw  = true;
            break;

          case 3: // Manual sleep
            goToSleep();
            break;
        }
      }
      break;
    }

    // ----------------------------------------------------------------
    case STATE_HABIT_SETTINGS: {
      if (forceRedraw) { drawHabitsApp(); forceRedraw = false; }

      if (events & EVT_NEXT_SHORT) {
        habitMenuIndex = (habitMenuIndex + 1) % NUM_HABITS;
        forceRedraw = true;
      } else if (events & EVT_SEL_SHORT) {
        habits[habitMenuIndex].active = !habits[habitMenuIndex].active;
        playVibe(pat_Tick);
        forceRedraw = true;
      }
      break;
    }

    // ----------------------------------------------------------------
    case STATE_ALARM: {
      if (forceRedraw) { drawAlarmScreen(); forceRedraw = false; }

      if (events & EVT_NEXT_SHORT) {
        // SNOOZE
        // [FIX 6] Store start time; elapsed check in habit engine is overflow-safe
        habits[activeHabitIndex].justSnoozed  = true;
        habits[activeHabitIndex].snoozeStartMs = millis();
        currentState = STATE_SNOOZE;
        playVibe(pat_Snooze);
        forceRedraw = true;

      } else if (events & (EVT_SEL_SHORT | EVT_SEL_LONG)) {
        // DISMISS
        stopVibe();
        habits[activeHabitIndex].justSnoozed = false;
        currentState = STATE_WATCHFACE;
        forceRedraw  = true;
      }
      break;
    }

    // ----------------------------------------------------------------
    case STATE_SNOOZE: {
      // [FIX 3] Non-blocking: draw once, then wait 2 seconds via timer
      if (forceRedraw) {
        drawSnoozeScreen();
        snoozeDisplayTimer = millis();
        forceRedraw = false;
      }
      if (millis() - snoozeDisplayTimer >= 2000UL) {
        currentState = STATE_WATCHFACE;
        forceRedraw  = true;
      }
      break;
    }

    // ----------------------------------------------------------------
    case STATE_SLEEP: {
      // Screen and motor are off. MCU stays alive to service millis() timers.
      // Button press woke us via EVT_ANY_PRESS -> wakeUpScreen() above.
      delay(10); // Minimal yield
      break;
    }

    default: break;
  }
}

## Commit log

2026-05-30 Implement HabitWatch OS v2.1 with various fixes
    This commit introduces the HabitWatch OS v2.1 for the Seeed Studio XIAO ESP32-C6 smartwatch. Key fixes include improved button event handling, non-blocking timers, and enhanced battery calculations.
    [firmwareOS.ino]
2026-06-06 repo finished
    [3D_PCB1_2026-06-01.step, Habitwatch Step 3d model with PCB.f3z, Habitwatch.step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]
2026-06-06 Add files via upload
    because stasis YSWS wouldn't accept easyeda format
    [Radio2.kicad_pcb]
